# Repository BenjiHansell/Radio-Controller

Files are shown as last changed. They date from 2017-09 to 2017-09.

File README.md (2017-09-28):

# Radio-Controller
A 3D printed radio controller with a custom PCB and firmware.  Click on one of the folders above for more details.

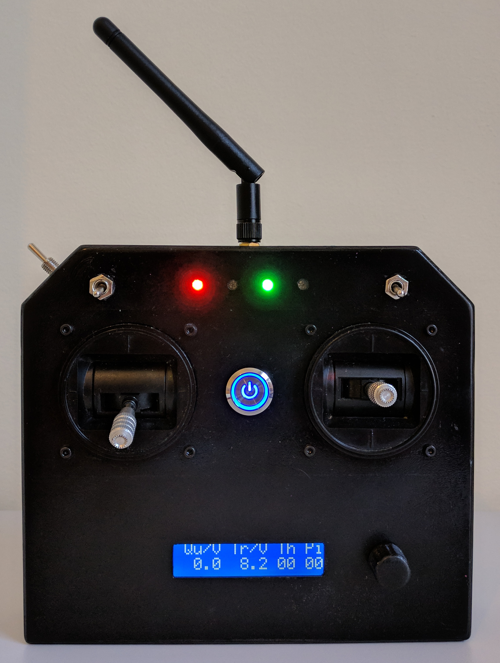
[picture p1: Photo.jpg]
Photo of Radio Controller


Video:

IMAGE ALT TEXT HERE (https://youtu.be/-YiaPBY8e_0)

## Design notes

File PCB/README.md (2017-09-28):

# PCB

The PCB is designed using KiCAD.  The schematic is based around that of the Arduino Pro Mini, with an ATmega328P clocked at 16 MHz on a 5V supply.  There are pin headers for connecting an SPI NRF24L01+ radio module (which has a dedicated 3.3V supply), an I2C LCD display, some LEDs, switches, analog sticks and a UART programmer.  There is a potential divider for reading the battery voltage.

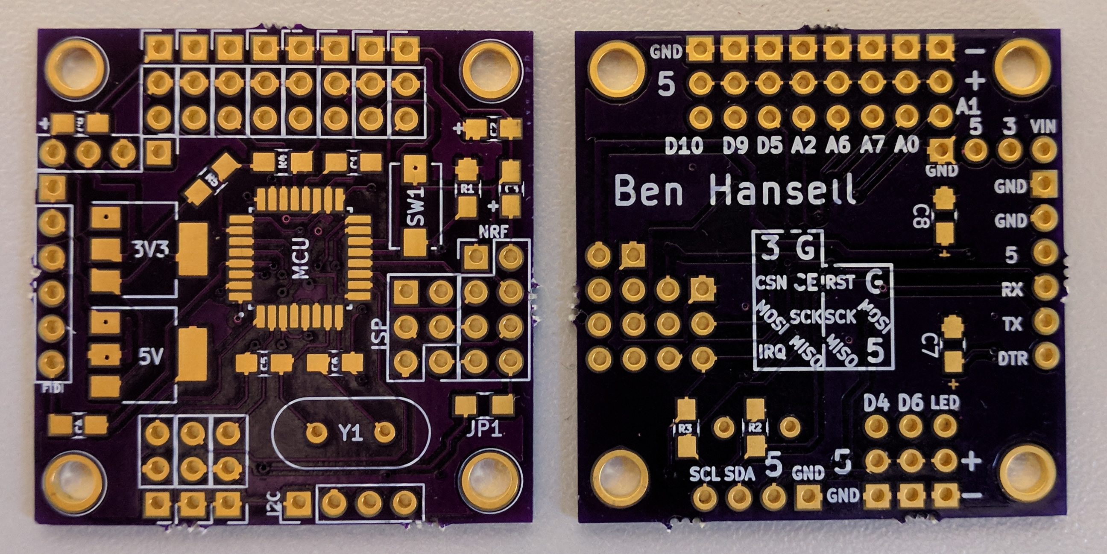
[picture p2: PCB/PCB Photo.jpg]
PCB Photo


## Order boards

I ordered my boards at OSH Park https://oshpark.com/shared_projects/BLpBqENQ

## Room for improvement

This PCB is the first iteration, with a few imperfections.  If I order more copies I will make the following minor modifications:
* A rectangular (rather than square) form factor would allow for more comfortable vertical mounting inside the radio controller
* The rotary encoder needs its own header with power, ground and 3 digital inputs
* PD0, PD1 and PD2 could be broken out for use with additional aux switches

## Long term improvements

The following major features could also be added later:
* A more powerful (yet inexpensive) MCU, such as the STM32F103C8T6
* 1S Li-Ion recharge and boost circuitry (via a USB-B or USB-C port)
* On-board programming (via the same USB port)

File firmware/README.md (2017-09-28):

# Firmware

The firmware is written in C++ using Platformio and the Arduino framework.  The code is object oriented with minimal use of the STL (as it runs on a microcontroller).

## Libraries

The following libraries are needed for the code to compile:

Library | Purpose | URL
------- | ------- | ---
StandardCplusplus | An STL port for Arduino | https://github.com/maniacbug/StandardCplusplus
RF24 | A driver for the NRF24L01+ radio module | https://github.com/nRF24/RF24
static_queue | My own implementation of std::queue for embedded systems | https://github.com/BenjiHansell/static_queue
NewliquidCrystal | A driver for the LCD | https://bitbucket.org/fmalpartida/new-liquidcrystal/wiki/Home
Adafruit_Neopixel | A driver for the LEDs | https://github.com/adafruit/Adafruit_NeoPixel

## Data Sources

The user interface is designed around inheritance from two base classes:
Any class which inherits from DataSource can provide data (e.g. telemetry, signal strength) for the LCD in the form of a string.  Any class which inherits from LedDataSource can be associated with an LED and provide data in the form of a colour.

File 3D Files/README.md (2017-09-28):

# 3D Design

The 3D design currently only comprises of two parts; a chasis and a back plate.  The analog sticks are not currently 3D printed, though I have made a few prototypes.

A third part which I used but did not design myself is [the knob for the rotary encoder](https://www.thingiverse.com/thing:646348).

I print the parts at a 0.3 mm layer height on a cheap FDM 3D printer and then sand and spray paint for a nice finish.

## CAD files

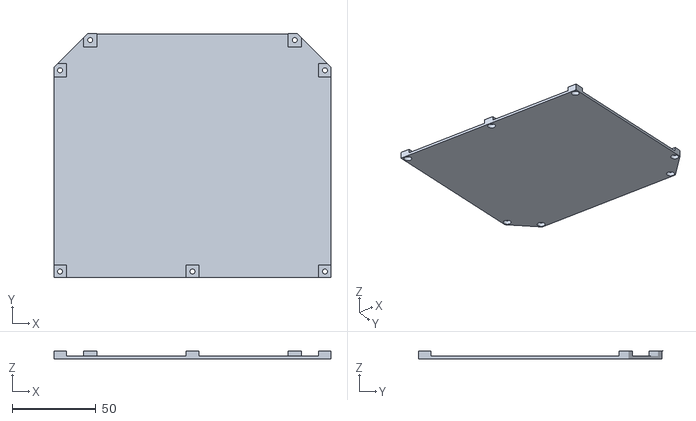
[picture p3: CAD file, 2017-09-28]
3D Files/Back Plate.stl
165.2 x 145.6 x 5.00

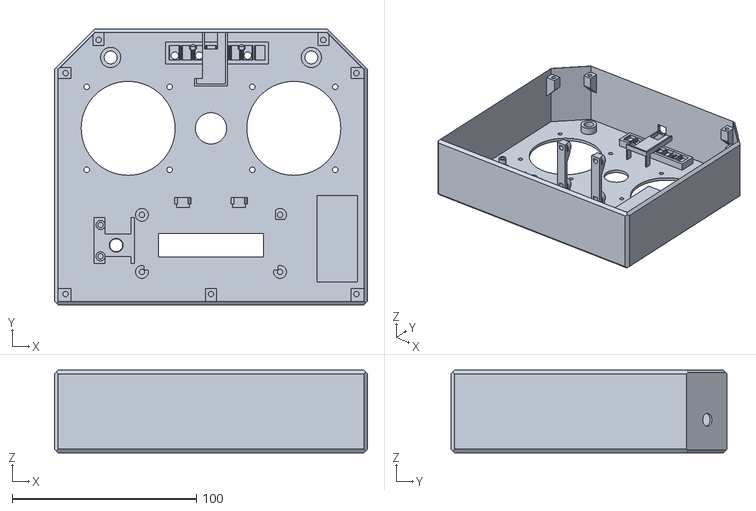
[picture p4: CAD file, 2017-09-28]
3D Files/Chasis.stl
170.0 x 150.0 x 45.0

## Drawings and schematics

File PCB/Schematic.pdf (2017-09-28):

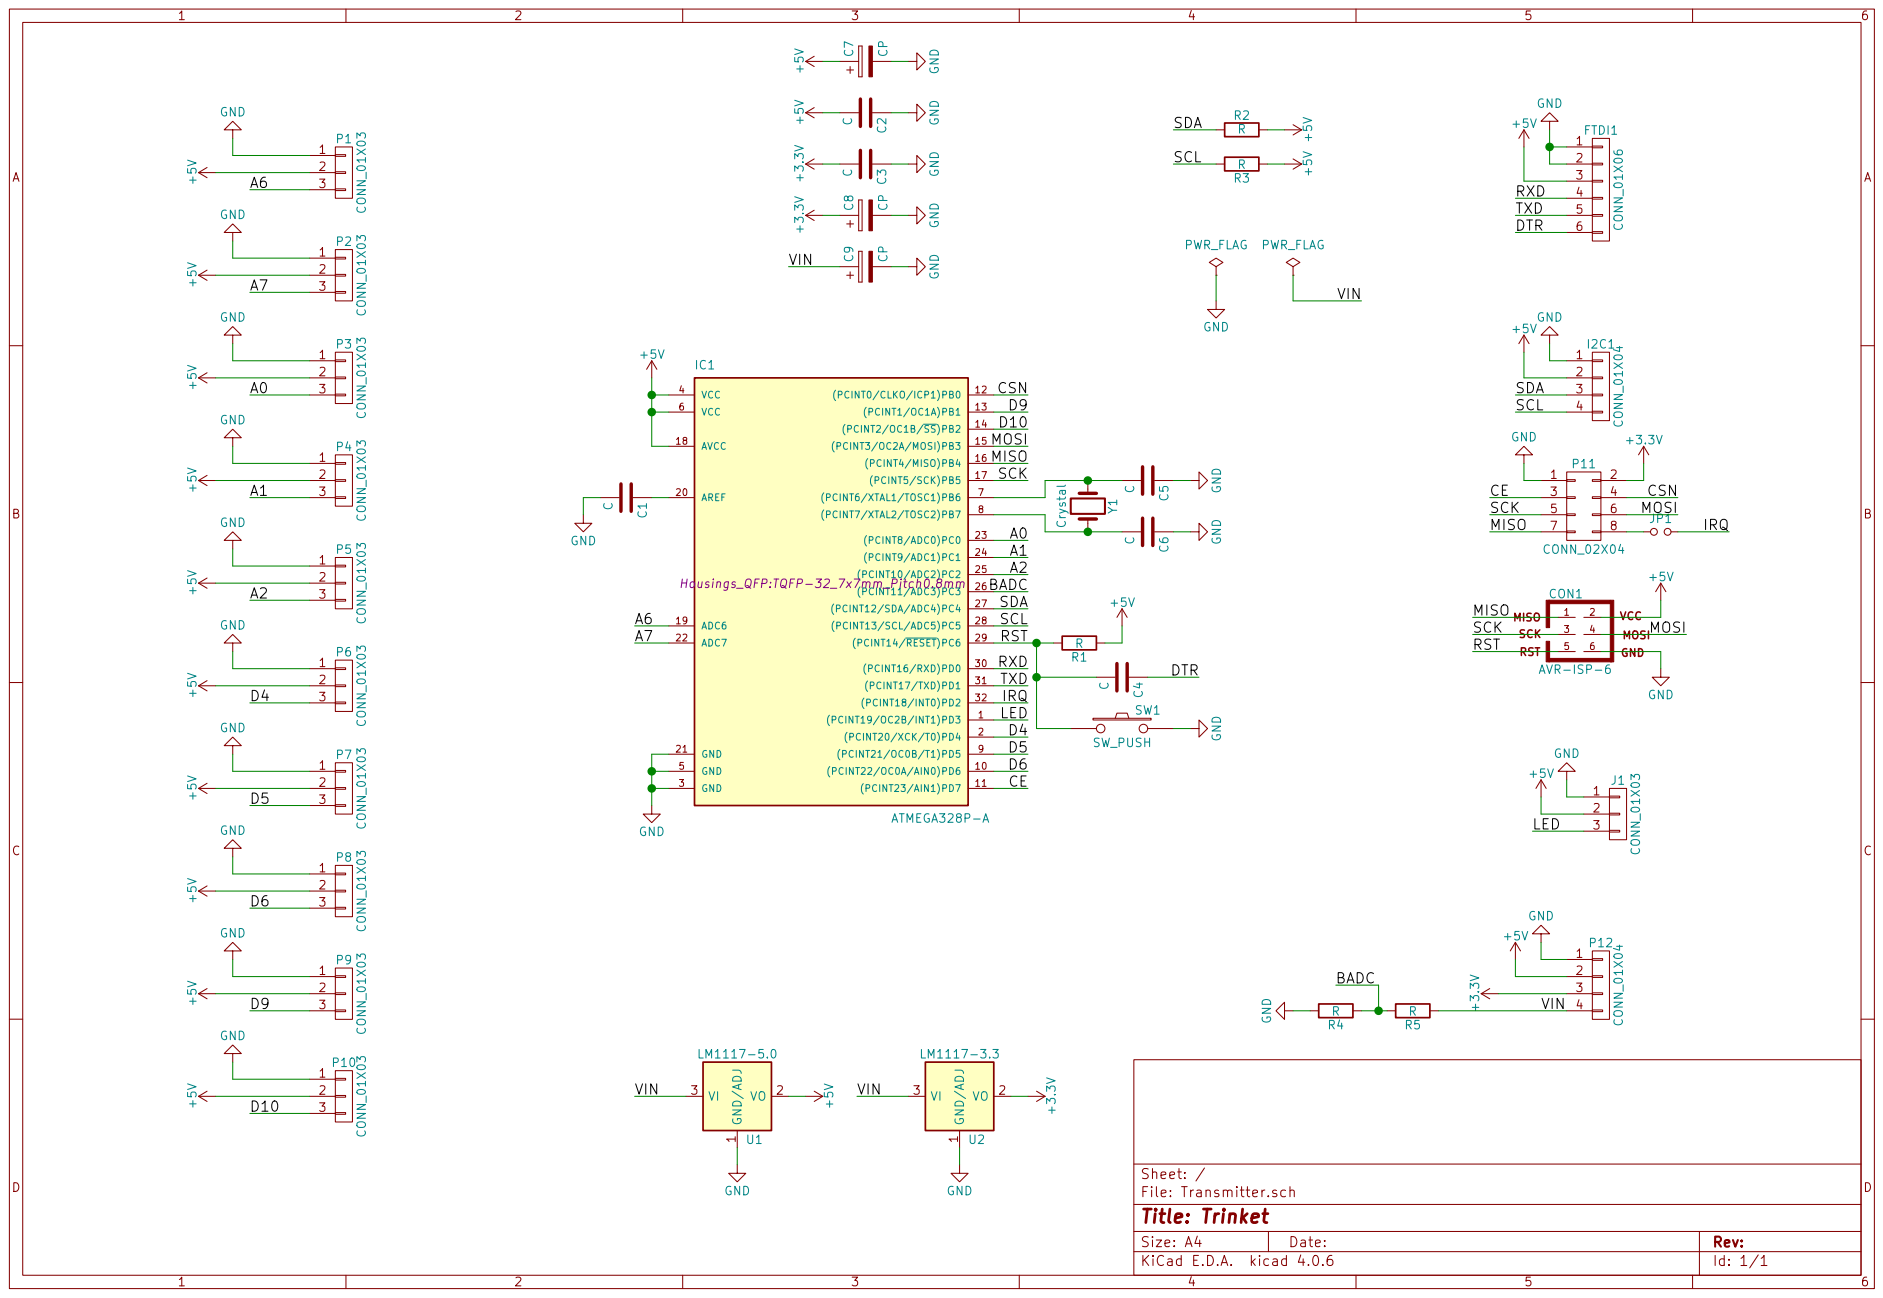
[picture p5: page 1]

Id: 1/1 Title: Trinket File: Transmitter.sch Sheet: /

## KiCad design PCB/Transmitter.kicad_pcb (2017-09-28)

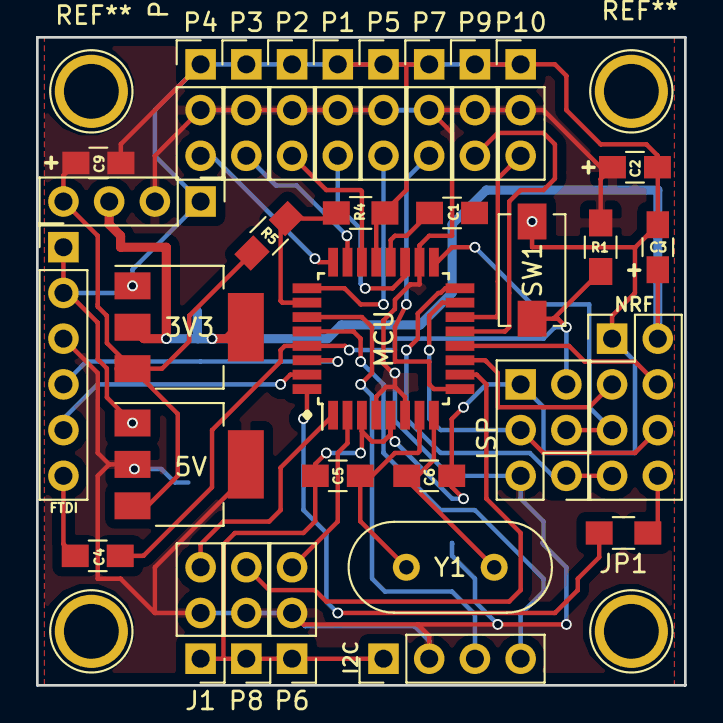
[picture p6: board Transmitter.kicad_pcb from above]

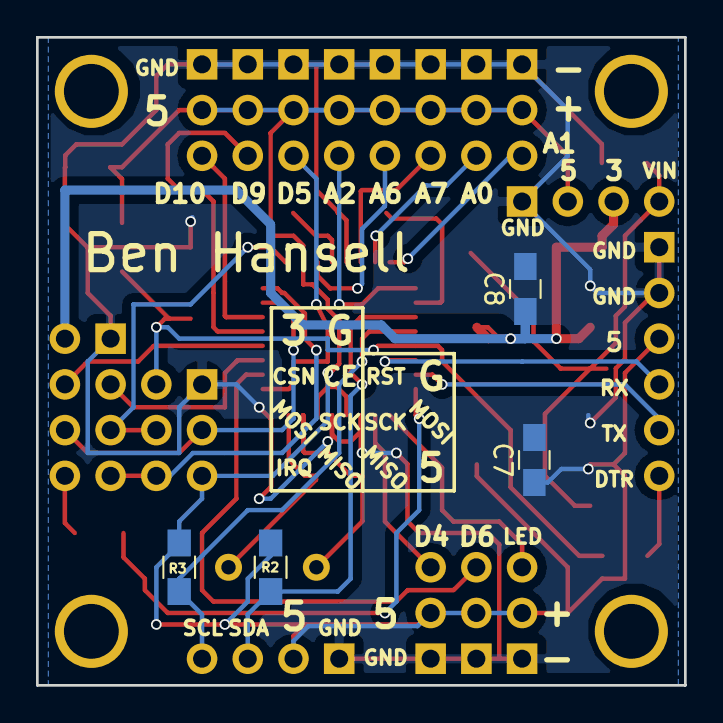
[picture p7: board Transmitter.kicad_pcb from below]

Board: 2 copper layers, 36.0 x 36.0 mm, 36 parts (4 on the bottom side), 32 nets.

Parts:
3V3: LM1117-3.3; SOT-223-3Lead_TabPin2
5V: LM1117-5.0; SOT-223-3Lead_TabPin2
C1, C2, C3, C4, C5, C6: C; C_0805_HandSoldering
C7, C8, C9: CP; C_0805_HandSoldering
FTDI: CONN_01X06; Pin_Header_Straight_1x06_Pitch2.54mm
I2C: CONN_01X04; Pin_Header_Straight_1x04_Pitch2.54mm
ISP: AVR-ISP-6; Pin_Header_Straight_2x03_Pitch2.54mm
J1: CONN_01X03; Pin_Header_Straight_1x03_Pitch2.54mm
JP1: Jumper_NO_Small; R_0805_HandSoldering
MCU: ATMEGA328P-A; TQFP-32_7x7mm_Pitch0.8mm
NRF: CONN_02X04; Pin_Header_Straight_2x04_Pitch2.54mm
P1, P2, P3, P4, P5, P6, P7, P8, P9, P10: CONN_01X03; Pin_Header_Straight_1x03_Pitch2.54mm
P12: CONN_01X04; Pin_Header_Straight_1x04_Pitch2.54mm
R1, R2, R3, R4, R5: R; R_0805_HandSoldering
SW1: SW_PUSH; SW_SPST_EVQPE1
Y1: Crystal; Crystal_HC49-U_Vertical

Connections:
+3V3: 3V3.2, C3.2, C8.1, NRF.2, P12.3
+5V: 5V.2, C2.2, C7.1, FTDI.3, I2C.2, ISP.2, J1.2, MCU.4, MCU.6, MCU.18, P1.2, P2.2, P3.2, P4.2, P5.2, P6.2, P7.2, P8.2, P9.2, P10.2, P12.2, R1.1, R2.2, R3.1
/A0: MCU.23, P3.3
/A1: MCU.24, P4.3
/A2: MCU.25, P5.3
/A6: MCU.19, P1.3
/A7: MCU.22, P2.3
/BADC: MCU.26, R4.1, R5.2
/CE: MCU.11, NRF.3
/CSN: MCU.12, NRF.4
/D4: MCU.2, P6.3
/D5: MCU.9, P7.3
/D6: MCU.10, P8.3
/D9: MCU.13, P9.3
/D10: MCU.14, P10.3
/DTR: C4.1, FTDI.6
/IRQ: JP1.2, MCU.32
/LED: J1.3, MCU.1
/MISO: ISP.1, MCU.16, NRF.7
/MOSI: ISP.4, MCU.15, NRF.6
/RST: C4.2, ISP.5, MCU.29, R1.2, SW1.1
/RXD: FTDI.4, MCU.30
/SCK: ISP.3, MCU.17, NRF.5
/SCL: I2C.4, MCU.28, R3.2
/SDA: I2C.3, MCU.27, R2.1
/TXD: FTDI.5, MCU.31
/VIN: 3V3.3, 5V.3, C9.1, P12.4, R5.1
GND: 3V3.1, 5V.1, C1.2, C2.1, C3.1, C5.1, C6.1, C7.2, C8.2, C9.2, FTDI.1, FTDI.2, I2C.1, ISP.6, J1.1, MCU.3, MCU.5, MCU.21, NRF.1, P1.1, P2.1, P3.1, P4.1, P5.1, P6.1, P7.1, P8.1, P9.1, P10.1, P12.1, R4.2, SW1.2
unnamed: C1.1, MCU.20
unnamed: C5.2, MCU.7, Y1.1
unnamed: C6.2, MCU.8, Y1.2
unnamed: JP1.1, NRF.8

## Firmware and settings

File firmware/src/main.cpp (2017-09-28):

/*
To do:
  - Add option to turn screen off
  - Check constness of member functions
*/

#include "DataSource/Battery/BatteryVehicle.hpp"
#include "DataSource/Battery/BatteryCell.hpp"
#include "DataSource/Battery/BatteryLocal.hpp"
#include "LedStrip.hpp"
#include "led_data_source.hpp"
#include "DataSource/DigitalSwitch.hpp"
#include "DataSource/SignalStrength.hpp"
#include "DataSource/frequency_counter.hpp"
#include "Wireless.hpp"
#include "DataSource/Stick/StickLoose.hpp"
#include "DataSource/Stick/StickCentred.hpp"
#include "page/PageStats.hpp"
#include "RotaryEncoder.hpp"
#include "Display.hpp"
#include "counter.hpp"
#include "DataSource.hpp"
#include "DataSource/Timer.hpp"
#include <Adafruit_NeoPixel.h>

#include <wire.h>
#include <LiquidCrystal_I2C.h>

#include "Arduino.h"

LiquidCrystal_I2C lcd(0x27, 2, 1, 0, 4, 5, 6, 7);

Wireless wireless(7, 8);

DigitalSwitch aux0(5, "A0", 0);
DigitalSwitch aux1(A2, "A1", 1);
DigitalSwitch aux2(0, "A2", 0);
StickLoose throttle(A7,"Th",0);
StickCentred roll (A1, "Ro", 1);
StickCentred yaw(A0, "Ya", 0);
StickCentred pitch(A6, "Pi", 0);

BatteryVehicle batteryVehicle("Qu/V");
BatteryCell batteryCell("Ce/V", batteryVehicle, 3);
BatteryLocal batteryLocal("Tr/V", A3, 97);
Timer timer(throttle);
SignalStrength signalStrength(wireless.transmissionFrequencyCounter, wireless.telemetryFrequencyCounter);

PageStats<14> page1;
Display<1> display;
LedStrip ledStrip(9, &signalStrength, nullptr, &batteryLocal, &batteryCell);

RotaryEncoder<3, 6, 4> rotaryEncoder;

void interruptWrapper(){ // to attach an interupt to a method, the method must be wrapped in a non-member function
  rotaryEncoder.refresh();
}

void setup() {
    // interupt attached for rotaryEncoder
    attachInterrupt(digitalPinToInterrupt(3), interruptWrapper, CHANGE);

    // initialising LCD library stuff
    lcd.begin(16, 2);
    lcd.setBacklightPin(3, POSITIVE);
    lcd.setBacklight(HIGH);

    // initialising radio
    wireless.begin();

    // initialising control inputs
    throttle.begin();
    pitch.begin();
    roll.begin();
    yaw.begin();
    aux0.begin();
    aux1.begin();
    aux2.begin();

    batteryLocal.begin();

    // initialising outputs
    display.setPage(0, &page1);
    ledStrip.begin();

    // associating data sources with stats page
    // in future this might be done in the constructor
    page1.addDataSource(&throttle);
    page1.addDataSource(&pitch);
    page1.addDataSource(&roll);
    page1.addDataSource(&yaw);
    page1.addDataSource(&aux0);
    page1.addDataSource(&aux1);
    page1.addDataSource(&aux2);
    page1.addDataSource(&timer);
    page1.addDataSource(&wireless.transmissionFrequencyCounter);
    page1.addDataSource(&wireless.telemetryFrequencyCounter);
    page1.addDataSource(&signalStrength);
    page1.addDataSource(&batteryVehicle);
    page1.addDataSource(&batteryCell);
    page1.addDataSource(&batteryLocal);

}

void loop(){
  Stick::new_loop(); // tells every Stick that the programs main loop has completed a cycle, this allows sticks to only access the ADC once per loop, no matter how many times they are read

  // transfering data from the control inputs to the radio
  wireless.controlPacket.throttle = throttle.read();
  wireless.controlPacket.pitch = pitch.read();
  wireless.controlPacket.roll = roll.read();
  wireless.controlPacket.yaw = yaw.read();
  wireless.controlPacket.aux0 = aux0.read() == 0 ? 0 : aux0.read() == 3 ? 1000 : 500;
  wireless.controlPacket.aux1 = aux1.read() == 0 ? 0 : aux1.read() == 3 ? 1000 : 500;
  wireless.controlPacket.aux2 = aux2.read();
  wireless.send();

  batteryVehicle.setValue(wireless.telemetryPacket.v_bat); // transfering the battery voltage from the radio to the DataSource which can be accessed by the display and LED

  ledStrip.update(); // the ledStrip will collect the data from its accosiated LedDataSources and update the LED outputs

  display.draw(lcd); // the display will collect the data from its associated DataSources and update the LCD accordingly

  display.move(rotaryEncoder.get()); // input data is transfered from the rotaryEncoder to the display for navigating the menu

}

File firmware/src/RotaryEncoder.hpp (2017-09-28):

#pragma once

#include "Arduino.h"

#include <StandardCplusplus.h>
#define STD_LIB_AVAILABLE // for static_queue.h
#include <static_queue.h>

enum direction{ up, down, left, right, none_vertical, none_horizontal, long_press };

struct rotary_encoder_snapshot{
  rotary_encoder_snapshot(bool _data = 1, bool _clock = 1, bool _sw = 1);
  bool data : 1;
  bool clock : 1;
  bool sw : 1;
  bool operator!=(const rotary_encoder_snapshot& rhs);
};

typedef decltype(millis()) time_t;

template<uint8_t pin_data, uint8_t pin_clock, uint8_t pin_switch>
class RotaryEncoder{
public:
  void begin();
  void refresh(); // takes a snapshot of the current pin states and records it for use in future calls of get(), should be attached to an interupt on either the data or clock pin
  direction get();
private:
  static_queue<rotary_encoder_snapshot, 20> record;
  bool previous_data = 1;
  bool previous_switch = 1;
  bool vertical = 0;
  bool long_press_has_been_acknowledged = 0;
  time_t time_button_was_last_not_pressed = 0;
};

template<uint8_t pin_data, uint8_t pin_clock, uint8_t pin_switch>
void RotaryEncoder<pin_data, pin_clock, pin_switch>::begin(){
  pinMode(pin_data, INPUT);
  pinMode(pin_clock, INPUT);
  pinMode(pin_switch, INPUT);
}

template<uint8_t pin_data, uint8_t pin_clock, uint8_t pin_switch>
void RotaryEncoder<pin_data, pin_clock, pin_switch>::refresh(){
  record.push(rotary_encoder_snapshot(digitalRead(pin_data), digitalRead(pin_clock), digitalRead(pin_switch)));
}

template<uint8_t pin_data, uint8_t pin_clock, uint8_t pin_switch>
direction RotaryEncoder<pin_data, pin_clock, pin_switch>::get(){
  time_t time_now = millis();
  if (long_press_has_been_acknowledged == 0 && time_now > time_button_was_last_not_pressed + 1000){
    long_press_has_been_acknowledged = 1;
    return long_press;
  }
  refresh();
  direction output = vertical ? none_vertical : none_horizontal;
  while (output == none_vertical || output == none_horizontal){
    if (record.empty()) return output;
    const rotary_encoder_snapshot& s = record.front();
    const bool current_data = s.data;
    const bool current_clock = s.clock;
    const bool current_switch = s.sw;
    if (current_switch) {
      time_button_was_last_not_pressed = time_now;
      long_press_has_been_acknowledged = 0;
    }
    record.pop();
    if(current_switch == 0 && current_switch != previous_switch) vertical = !vertical;
    previous_switch = current_switch;
    if(current_data == 0 && previous_data == 1){
      if (vertical == true){
        output = current_clock ? down : up;
      } else {
        output = current_clock ? left : right;
      }
    }
    previous_data = current_data;
  }
  return output;
}
